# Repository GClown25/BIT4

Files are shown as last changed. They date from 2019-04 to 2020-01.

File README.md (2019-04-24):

# BIT4
BIT4 is a 4Bit microcontroller - fully programmable with only three buttons.

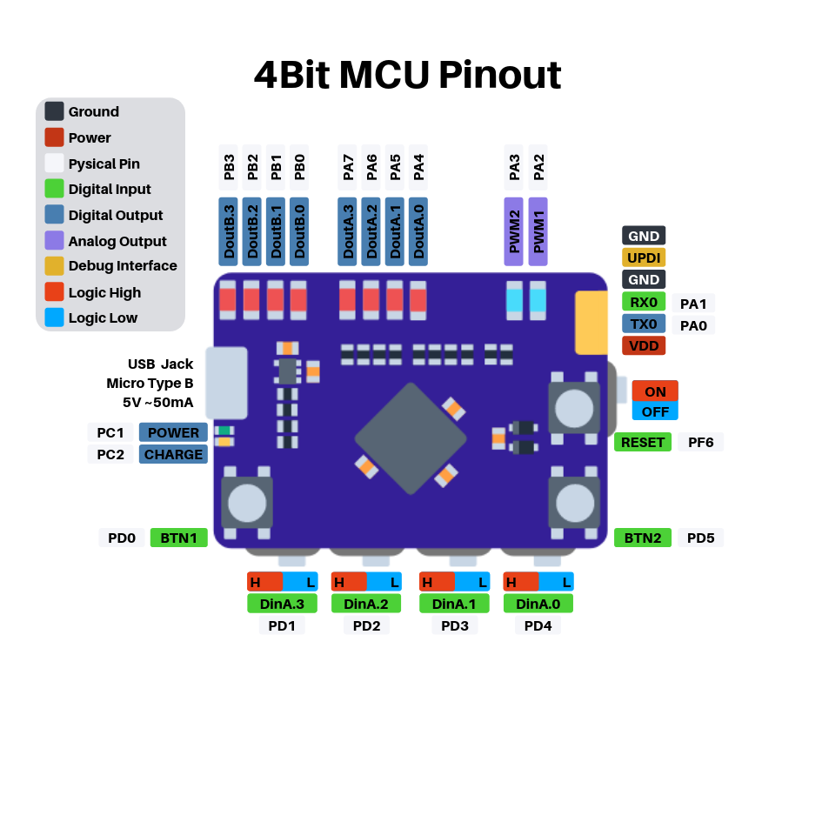
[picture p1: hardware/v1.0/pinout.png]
pinout


# Programming guide:

The BIT4 microcontroller has 256 Bytes of programm memory, split in 16 pages with each 16 instructions.
A instruction is 8bit wide and consists of an command and data:
\
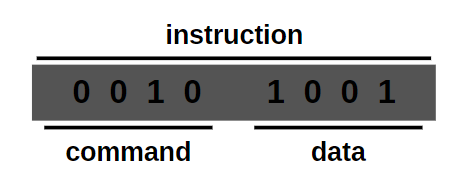
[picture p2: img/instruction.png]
instruction

\
To enter the programming mode, hold BTN2 down, press the RESET button once and then release BTN2.
In programming mode, step through the instructions with BTN2. When going to a new instruction, 
the leds will show the current address for a fraktion of a second.
With BTN1 the value of the command and data of the current instruction can be changed.
When stepping to a new address with BTN2, the instuction of the address above gets saved in the EEPROM.
At the end, press RESET to leave the programming mode and to start the programm execution.

## Instruction set explained:

- command 0x0: load a constant value to doutB
- command 0x1: load a constant value to doutA
- command 0x2: delay
- command 0x3: do a relative jump back
- command 0x4: load constant value to variable A
- command 0x5: load something with the value of variable A
- command 0x6: load the value of something into the variable A
- command 0x7: do arithmetic and logic operations with variable A (and B)
- command 0x8: set the high nibble of the address to jump to in absolute jump instructions
- command 0x9: do an absolute jump to the specified address
- command 0xA, 0xB: acts like a for loop. Every time this command is executed,
  if the variable C (or D) is greater than zero, an absolute jump to the specified address is done.
  Then the variable C (or D) gets decremented. 
- command 0xC: skip the next instruction if the argument is true
- command 0xD: call a function at the specified address
- command 0xE: return from the function call
- command 0xF: sets the address of the virtual 4bit RAM. 
  The value stored in this address can be read with 0x6e and written with 0x50.

## Examples:

**Blinki:**

| address | instruction | comment |
| :--- | :--- | ---: |
| 0 | 1f |  turn all leds on doutA on |
| 1 | 28 | wait for 500ms |
| 2 | 10 | turn all leds on doutB off |
| 3 | 28 | wait for 500ms |
| 4 | 34 | relative jump -4 |

\
**Binary counter:**
\
https://www.youtube.com/watch?v=6CpZszKlP7Y

| address | instruction | comment |
| :--- | :--- | ---: |
| 0 | 5B | DoutB = A |
| 1 | 59 | PWM1 = A |
| 2 | 71 | A++ |
| 3 | 28 | wait for 500ms |
| 4 | 34 | relative jump -4 |

\
**Blinki with adjustable speed:**
\
https://www.youtube.com/watch?v=YPoedGGZs4g

| address | instruction | comment |
| :--- | :--- | ---: |
| **main:** |
| 0 | 10 | DoutA = 0x0 |
| 1 | d5 | call myWait |
| 2 | 1f | DoutA = 0xf |
| 3 | d5 | call myWait |
| 4 | 34 | relative jump -4 |
| **myWait:** |
| 5 | 64 | A = Din |
| 6 | 52 | C = A |
| 7 | 25 | wait for 50ms |
| 8 | a7 | for(C > 0; C--) jmp 7 |
| 9 | e0 | return |

\
**Credits:**\
The idea for this project came from the german microcontroller learning plattform "TPS" (http://elektronik-labor.de/Lernpakete/TPS/TPS0.html).

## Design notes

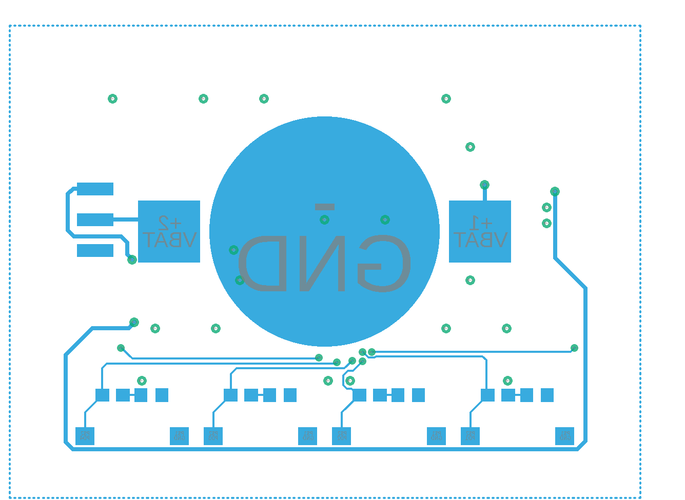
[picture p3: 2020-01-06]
hardware/v1.1b/layout_bot.png

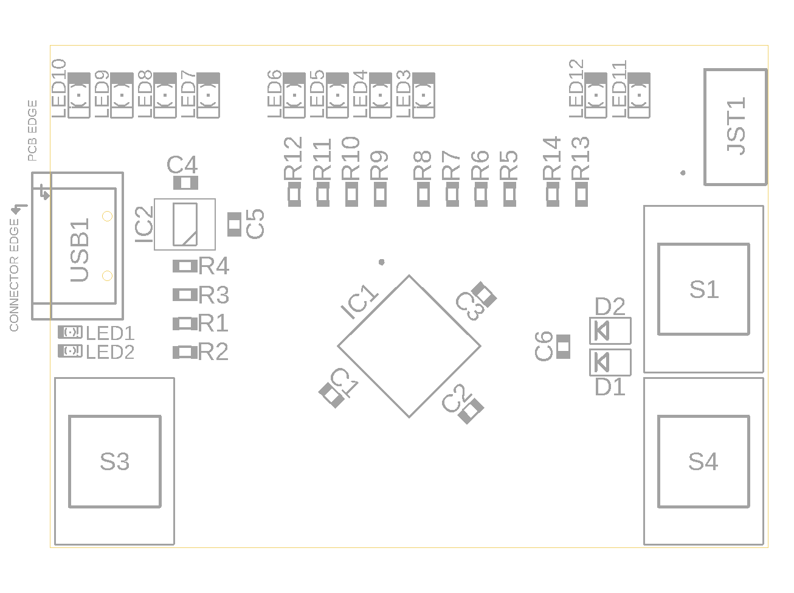
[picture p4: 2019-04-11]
hardware/v1.0/place_top.png

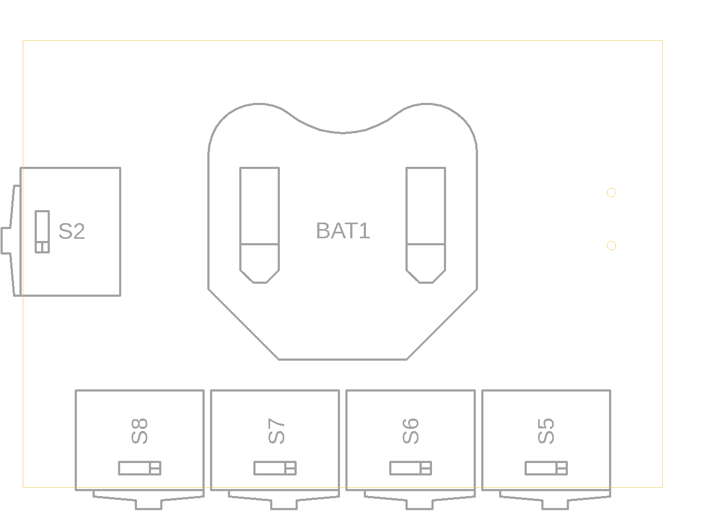
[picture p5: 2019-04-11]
hardware/v1.0/place_bot.png

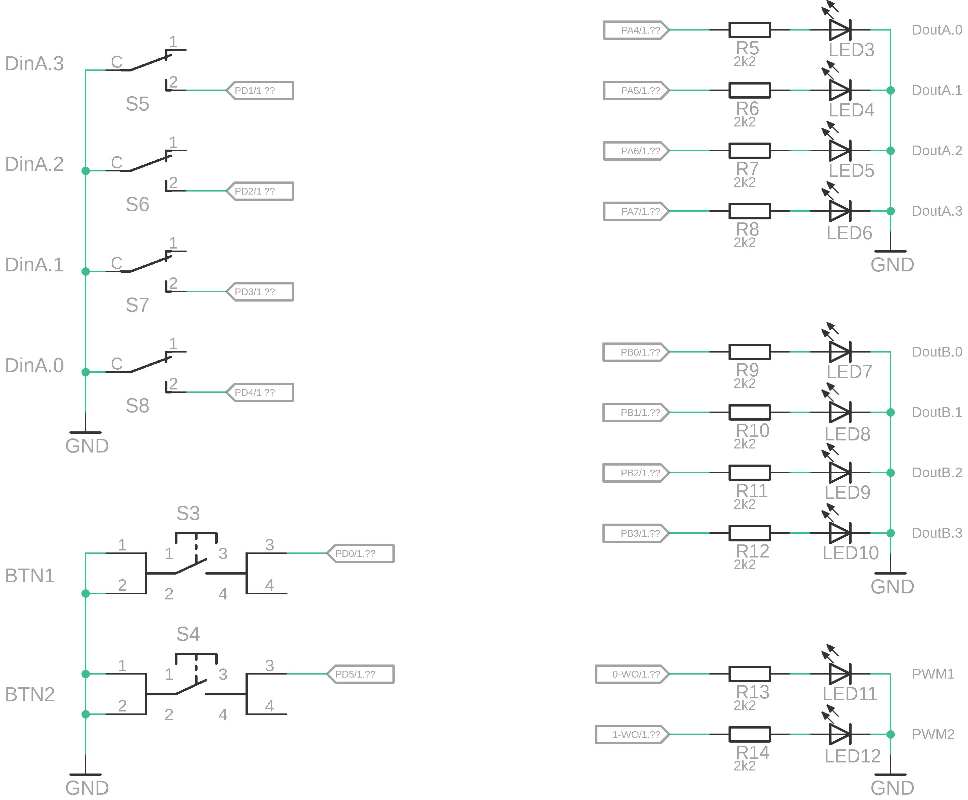
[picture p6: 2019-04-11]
hardware/v1.0/schematic3.png

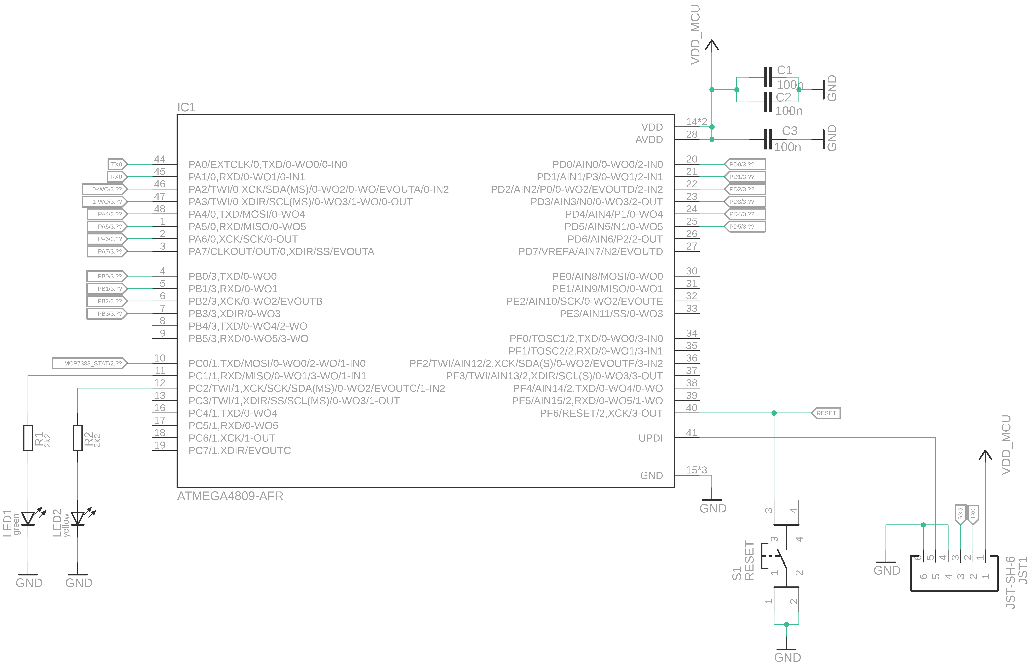
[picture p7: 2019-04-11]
hardware/v1.0/schematic1.png

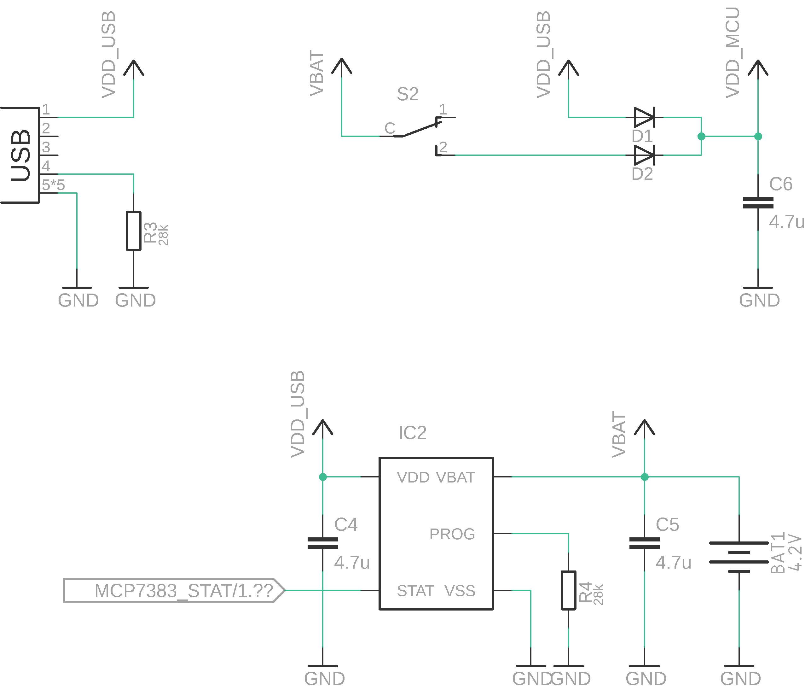
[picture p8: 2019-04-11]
hardware/v1.1b/schematic_2.png

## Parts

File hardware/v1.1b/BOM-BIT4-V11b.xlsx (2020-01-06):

pieces | identifier | name | package | prize/piece | prize | link
1 | IC1 | Atmega4809 | TQFP 48-Pin | 1.34 € | 1.34 € | https://www.mouser.at/ProductDetail/556-ATMEGA4809-AFR
1 | IC2 | MCP7383 Li-ion charger | SOT23-5 | 0.41 € | 0.41 € | https://www.reichelt.at/battery-management-ic-li-ion-sot-23-5-mcp-73831t-2aci-p217314.html?trstct=pos_0
1 | USB1 | micro usb type B | smd | 0.78 € | 0.78 € | https://www.mouser.at/ProductDetail/538-47346-0001
1 | JST1 | JST-SH-6 connector | smd 90° | 0.56 € | 0.56 € | https://at.rs-online.com/web/p/leiterplatten-header/5468827/?searchHistory=%7B%22enabled%22%3Atrue%7D
1 | BAT1 | cell battery clip 20mm | smd | 0.25 € | 0.25 € | https://www.mouser.at/ProductDetail/712-BAT-HLD-001
2 | D1, D2 | MBR0530T1G schottky diode | SOD-123 | 0.07 € | 0.14 € | https://www.reichelt.at/schottkydiode-30-v-0-5-a-sod-123-mbr0530t1g-ons-p219621.html?&trstct=pos_0
3 | S1, S3, S4 | button 6x6x4.3 mm | smd | 0.28 € | 0.84 € | https://www.reichelt.at/taster-smd-1-schliesser-no-omr-b3fs-1012p-p243058.html?&trstct=pol_2
4 | U$1-U$4 | button 3x6x2.5mm | smd | 0.03 € | 0.12 € | https://www.banggood.com/100pcs-3-x-6-x-2_5mm-DC-12V-0_5A-SMD-Tact-Push-Button-Switch-p-1202259.html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
1 | S2 | switch 10x6.5x2.5 mm | smd | 1.00 € | 1.00 € | https://www.reichelt.at/schiebeschalter-1x-um-liegend-smd-ss-smd402-p112181.html?&trstct=pol_1
1 | LED1 | led green | 0603 | 0.07 € | 0.07 € | https://www.reichelt.at/led-smd-0603-gruen-16-mcd-100-evl-19-21sygc-p231658.html?&trstct=pos_0
1 | LED2 | led yellow | 0603 | 0.07 € | 0.07 € | https://www.reichelt.at/led-smd-0603-gelb-16-mcd-100-evl-19-21uyc-s5-p231661.html?&trstct=pos_0
4 | LED3-LED6 | led DoutA | 1206 | 0.08 € | 0.32 € | https://www.reichelt.at/led-smd-1206-rot-62-mcd-60-evl-11-21sdrc-p231607.html?&trstct=pos_0
4 | LED7-LED10 | led DoutB | 1206 | 0.08 € | 0.32 € | https://www.reichelt.at/led-smd-1206-rot-62-mcd-60-evl-11-21sdrc-p231607.html?&trstct=pos_0
4 | LED13-LED16 | led DinA | 1206 | 0.09 € | 0.36 € | https://www.reichelt.at/led-smd-1206-gruen-44-mcd-60-evl-11-21sygc-s2-p231611.html?r=1
2 | LED11, LED12 | led PWM | 1206 | 0.36 € | 0.72 € | https://www.reichelt.at/led-smd-1206-blau-44-mcd-20-evl-11-21ubc-c4-p231612.html?&trstct=pos_0
2 | R3, R4 | resistor 28k | 0603 | 0.02 € | 0.04 € | https://www.reichelt.at/smd-widerstand-0603-28-0-kohm-100-mw-1-rnd-0603-1-28k-p213128.html?trstct=pos_0
16 | R1, R2, R5-R18 | resistor 2k2 | 0603 | 0.02 € | 0.32 € | https://www.reichelt.at/smd-widerstand-0603-2-2-kohm-100-mw-1-rnd-0603-1-2-2k-p183061.html?trstct=pos_0
4 | R19-R22 | resistor 100R | 0603 | 0.02 € | 0.08 € | https://www.reichelt.at/smd-widerstand-0603-100-ohm-100-mw-1-rnd-0603-1-100-p183013.html?trstct=pol_0
3 | C4-C6 | capacitor 4u7 | 0603 | 0.07 € | 0.21 € | https://www.reichelt.at/vielschicht-kerko-4-7-f-10v-85-c-kem-x5r0603-4-7u-p207009.html?&trstct=pos_0
7 | C1-C3, C7-C10 | capacitor 100n | 0603 | 0.02 € | 0.14 € | https://www.reichelt.at/smd-vielschicht-keramikkondensator-100n-10-x7r-g0603-100n-p31873.html?trstct=pos_0
 |  |  |  |  | 8.09 €

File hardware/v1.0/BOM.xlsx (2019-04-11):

pieces | identifier | name | package | prize/piece | prize | link
1 | IC1 | Atmega4809 | TQFP 48-Pin | 1.61 € | 1.61 € | https://at.rs-online.com/web/p/products/1753197/
1 | IC2 | MCP7383 Li-ion charger | SOT23-5 | 0.41 € | 0.41 € | https://www.reichelt.at/battery-management-ic-li-ion-sot-23-5-mcp-73831t-2aci-p217314.html?trstct=pos_0
1 | USB1 | micro usb type B | smd | 1.84 € | 1.84 € | https://at.rs-online.com/web/p/micro-usb-steckverbinder/8183361/?searchHistory=%7B%22enabled%22%3Atrue%7D
1 | JST1 | JST-SH-6 connector | smd 90° | 0.56 € | 0.56 € | https://at.rs-online.com/web/p/leiterplatten-header/5468827/?searchHistory=%7B%22enabled%22%3Atrue%7D
1 | BAT1 | cell battery clip 20mm | smd | 0.33 € | 0.33 € | https://www.reichelt.at/knopfzellenclip-fuer-20-mm-smd-kzh-20smd-p56574.html?&trstct=pol_8
2 | D1, D2 | MBR0530T1G schottky diode | SOD-123 | 0.07 € | 0.14 € | https://www.reichelt.at/schottkydiode-30-v-0-5-a-sod-123-mbr0530t1g-ons-p219621.html?&trstct=pos_0
3 | S1, S3, S4 | button 6x6x4.3 mm | smd | 0.28 € | 0.84 € | https://www.reichelt.at/taster-smd-1-schliesser-no-omr-b3fs-1012p-p243058.html?&trstct=pol_2
5 | S2, S5-S8 | switch 10x6.5x2.5 mm | smd | 1.00 € | 5.00 € | https://www.reichelt.at/schiebeschalter-1x-um-liegend-smd-ss-smd402-p112181.html?&trstct=pol_1
1 | LED1 | led green | 0603 | 0.07 € | 0.07 € | https://www.reichelt.at/led-smd-0603-gruen-16-mcd-100-evl-19-21sygc-p231658.html?&trstct=pos_0
1 | LED2 | led yellow | 0603 | 0.07 € | 0.07 € | https://www.reichelt.at/led-smd-0603-gelb-16-mcd-100-evl-19-21uyc-s5-p231661.html?&trstct=pos_0
8 | LED3-LED10 | led (any color) | 1206 | 0.10 € | 0.80 € | https://www.reichelt.at/led-smd-1206-gelb-29-mcd-60-evl-11-21uyc-s52-p231614.html?&trstct=pos_0
2 | LED11, LED12 | led (any color) | 1206 | 0.36 € | 0.72 € | https://www.reichelt.at/led-smd-1206-blau-44-mcd-20-evl-11-21ubc-c4-p231612.html?&trstct=pos_0
2 | R3, R4 | resistor 28k | 0603 | 0.02 € | 0.04 € | https://www.reichelt.at/smd-widerstand-0603-28-0-kohm-100-mw-1-rnd-0603-1-28k-p213128.html?trstct=pos_0
12 | R1, R2, R4-R14 | resistor 2k2 | 0603 | 0.02 € | 0.24 € | https://www.reichelt.at/smd-widerstand-0603-2-2-kohm-100-mw-1-rnd-0603-1-2-2k-p183061.html?trstct=pos_0
3 | C4-C6 | capacitor 4u7 | 0603 | 0.07 € | 0.21 € | https://www.reichelt.at/vielschicht-kerko-4-7-f-10v-85-c-kem-x5r0603-4-7u-p207009.html?&trstct=pos_0
3 | C1-C3 | capacitor 100n | 0603 | 0.02 € | 0.06 € | https://www.reichelt.at/smd-vielschicht-keramikkondensator-100n-10-x7r-g0603-100n-p31873.html?trstct=pos_0
 |  |  |  |  | 12.94 €

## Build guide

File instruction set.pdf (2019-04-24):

basic stuff | prog flow doing sth with variables | prog flow | for loop | prog flow function call and return | storage
command -> | 0 | 1 | 2 | 3 | 4 | 5 | 6 | 7 | 8 | 9 | A | B | C | D | E | F
data \/ | DoutB= | DoutA= | Wait | rel jump -n | A= | ... =A | A= ... | A= ... | Set Page | Jump to | C* | D* | Skip if ... | Call | Ret | Set RAM R/W Addr
0 | 0 | 0 | 1 ms | 0 | 0 | RAM = A | | | 0 | 0 | 0 | 0 | | 0 | 0 | 0
1 | 1 | 1 | 2 ms | 1 | 1 | B=A | A= B | A=A+1 | 1 | 1 | 1 | 1 | A>B | 1 | | 1
2 | 2 | 2 | 5 ms | 2 | 2 | C=A | A=C | A=A–1 | 2 | 2 | 2 | 2 | A<B | 2 | | 2
3 | 3 | 3 | 10 ms | 3 | 3 | D=A | A=D | A=A+B | 3 | 3 | 3 | 3 | A==B | 3 | | 3
4 | 4 | 4 | 20 ms | 4 | 4 | DoutA=A | A=Din | A=A–B | 4 | 4 | 4 | 4 | A != B | 4 | | 4
5 | 5 | 5 | 50 ms | 5 | 5 | DoutA.0=A.0 | A=Din.0 | A= A*B | 5 | 5 | 5 | 5 | A = 0 | 5 | | 5
6 | 6 | 6 | 100 ms | 6 | 6 | DoutA.1=A.0 | A=Din.1 | A=A/B | 6 | 6 | 6 | 6 | A != 0 | 6 | | 6
7 | 7 | 7 | 200 ms | 7 | 7 | DoutA.2=A.0 | A=Din.2 | A=A And B | 7 | 7 | 7 | 7 | | 7 | | 7
8 | 8 | 8 | 500 ms | 8 | 8 | DoutA.3= A.0 | A=Din.3 | A=A Or B | 8 | 8 | 8 | 8 | Din.0=0 | 8 | | 8
9 | 9 | 9 | 1 s | 9 | 9 | PWM1=A | | A= A Xor B | 9 | 9 | 9 | 9 | Din.1=0 | 9 | | 9
A | 10 | 10 | 2 s | 10 | 10 | PWM2=A | | A=Not A | A | A | A | A | Din.2=0 | A | | A
B | 11 | 11 | 5 s | 11 | 11 | DoutB=A | A = randNr | A = A mod B | B | B | B | B | Din.3=0 | B | | B
C | 12 | 12 | 10 s | 12 | 12 | DoutB.0=A.0 | A = DoutA | A = A << 1 | C | C | C | C | BTN1=0 | C | | C
D | 13 | 13 | 20 s | 13 | 13 | DoutB.1=A.0 | A = DoutB | A = A >> 1 | D | D | D | D | BTN2=0 | D | | D
E | 14 | 14 | 30 s | 14 | 14 | DoutB.2=A.0 | A = RAM | A = A <<B | E | E | E | E | BTN1=1 | E | | E
F | 15 | 15 | 60 s | 15 | 15 | DoutB.3= A.0 | A = RAM[B] | A = A >> B | F | F | F | F | BTN2=1 | F | | F

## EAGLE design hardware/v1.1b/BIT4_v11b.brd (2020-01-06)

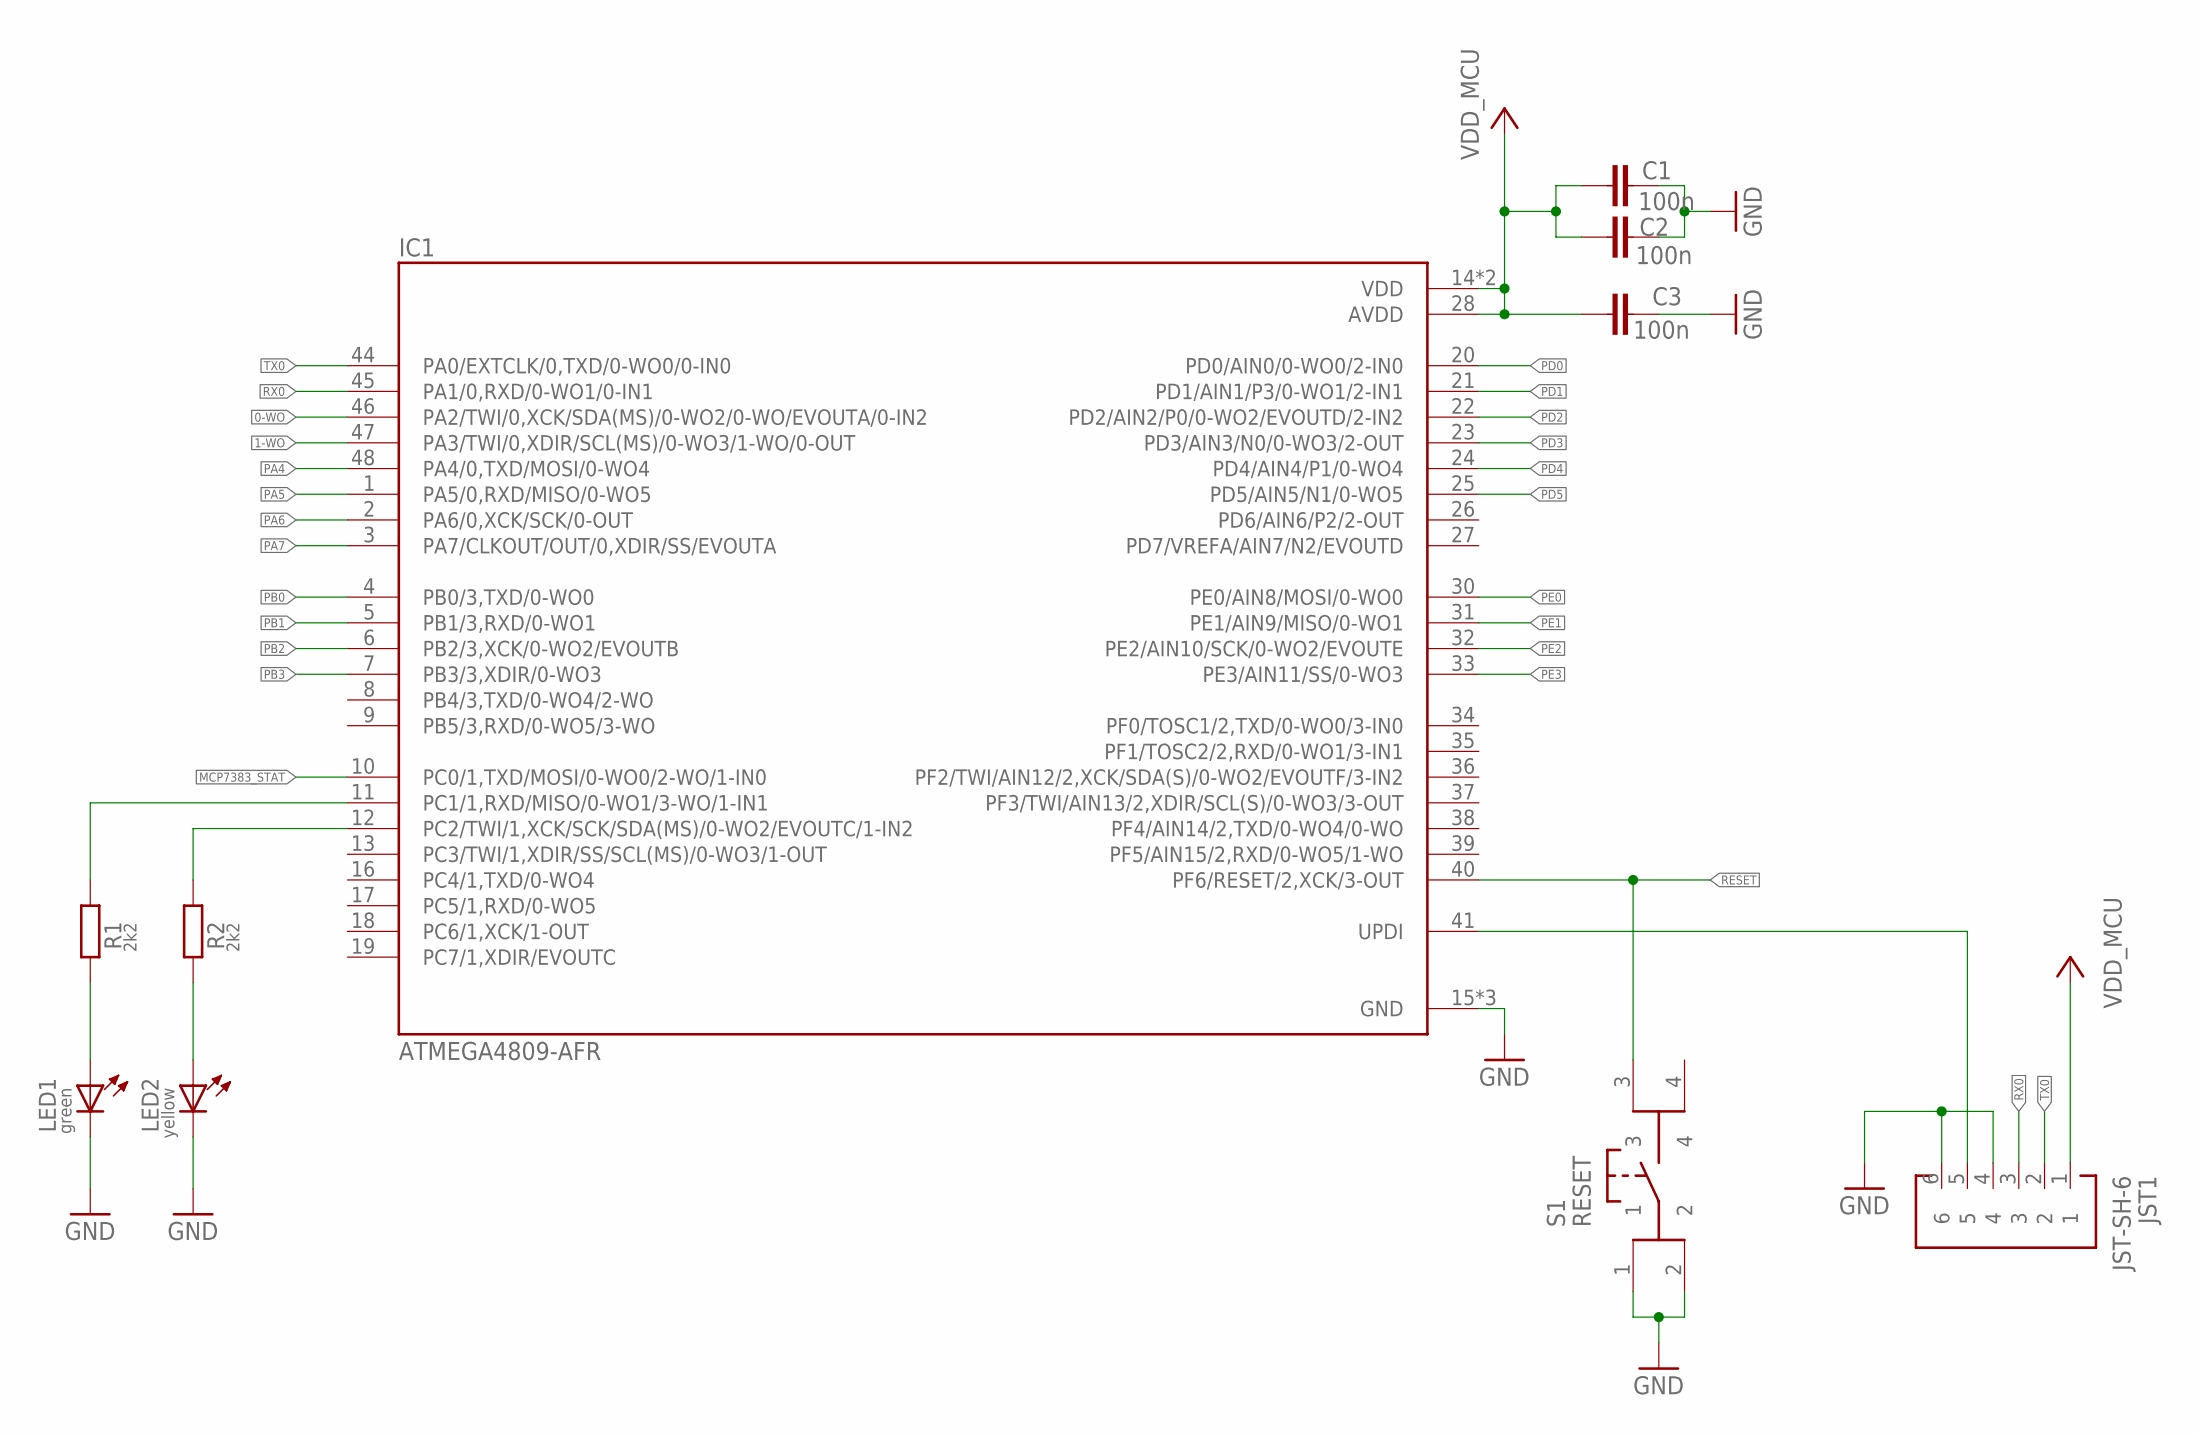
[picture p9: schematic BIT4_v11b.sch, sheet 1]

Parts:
C1, C2, C3: 100n; C0603
IC1: ATMEGA4809-AFR; QFP50P900X900X120-48N
JST1: JST-SH-6
LED1: green; LED_0603
LED2: yellow; LED_0603
R1, R2: 2k2; R0603
S1: RESET; B3FS-1012

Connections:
0-WO: IC1.46 (PA2/TWI/0,XCK/SDA(MS)/0-WO2/0-WO/EVOUTA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); also elsewhere on the board
1-WO: IC1.47 (PA3/TWI/0,XDIR/SCL(MS)/0-WO3/1-WO/0-OUT); also elsewhere on the board
GND: C1.2, C2.2, C3.2, IC1.15 (GND), IC1.29 (GND), IC1.43 (GND), JST1.4, JST1.6, LED1.C, LED2.C, S1.1, S1.2; also elsewhere on the board
MCP7383_STAT: IC1.10 (PC0/1,TXD/MOSI/0-WO0/2-WO/1-IN0); also elsewhere on the board
unnamed: LED2.A, R2.1
unnamed: LED1.A, R1.1
unnamed: IC1.12 (PC2/TWI/1,XCK/SCK/SDA(MS)/0-WO2/EVOUTC/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), R2.2
unnamed: IC1.11 (PC1/1,RXD/MISO/0-WO1/3-WO/1-IN1), R1.2
PA4: IC1.48 (PA4/0,TXD/MOSI/0-WO4); also elsewhere on the board
PA5: IC1.1 (PA5/0,RXD/MISO/0-WO5); also elsewhere on the board
PA6: IC1.2 (PA6/0,XCK/SCK/0-OUT); also elsewhere on the board
PA7: IC1.3 (PA7/CLKOUT/OUT/0,XDIR/SS/EVOUTA); also elsewhere on the board
PB0: IC1.4 (PB0/3,TXD/0-WO0); also elsewhere on the board
PB1: IC1.5 (PB1/3,RXD/0-WO1); also elsewhere on the board
PB2: IC1.6 (PB2/3,XCK/0-WO2/EVOUTB); also elsewhere on the board
PB3: IC1.7 (PB3/3,XDIR/0-WO3); also elsewhere on the board
PD0: IC1.20 (PD0/AIN0/0-WO0/2-IN0); also elsewhere on the board
PD1: IC1.21 (PD1/AIN1/P3/0-WO1/2-IN1); also elsewhere on the board
PD2: IC1.22 (PD2/AIN2/P0/0-WO2/EVOUTD/2-IN2); also elsewhere on the board
PD3: IC1.23 (PD3/AIN3/N0/0-WO3/2-OUT); also elsewhere on the board
PD4: IC1.24 (PD4/AIN4/P1/0-WO4); also elsewhere on the board
PD5: IC1.25 (PD5/AIN5/N1/0-WO5); also elsewhere on the board
PE0: IC1.30 (PE0/AIN8/MOSI/0-WO0); also elsewhere on the board
PE1: IC1.31 (PE1/AIN9/MISO/0-WO1); also elsewhere on the board
PE2: IC1.32 (PE2/AIN10/SCK/0-WO2/EVOUTE); also elsewhere on the board
PE3: IC1.33 (PE3/AIN11/SS/0-WO3); also elsewhere on the board
RESET: IC1.40 (PF6/RESET/2,XCK/3-OUT), S1.3
RX0: IC1.45 (PA1/0,RXD/0-WO1/0-IN1), JST1.3
TX0: IC1.44 (PA0/EXTCLK/0,TXD/0-WO0/0-IN0), JST1.2
UPDI: IC1.41 (UPDI), JST1.5
VDD_MCU: C1.1, C2.1, C3.1, IC1.14 (VDD), IC1.28 (AVDD), IC1.42 (VDD), JST1.1; also elsewhere on the board

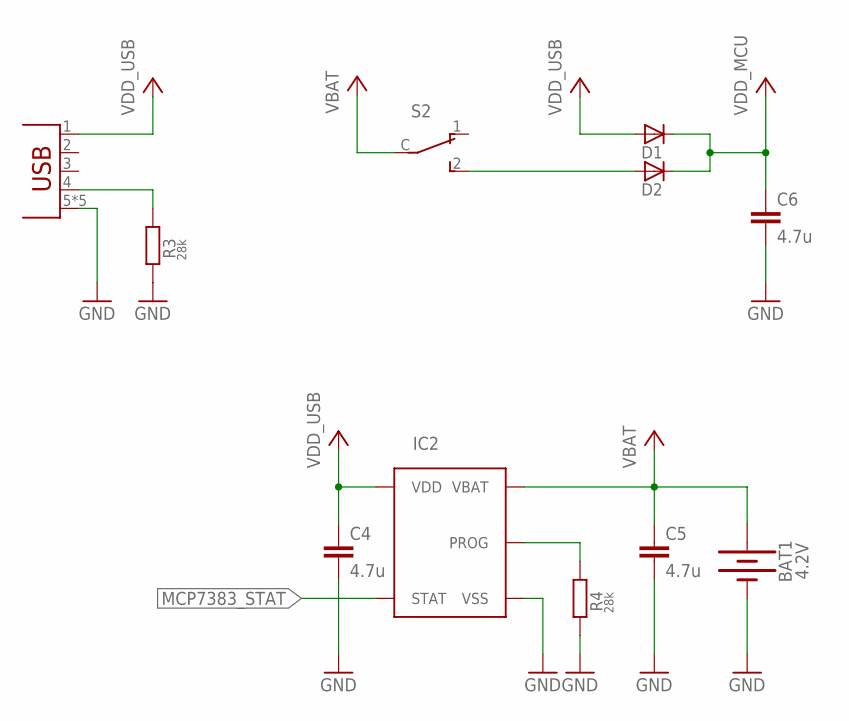
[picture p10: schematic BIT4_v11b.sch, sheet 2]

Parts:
BAT1: 4.2V; CELL-CLIP_PAD_20MM
C4, C5, C6: 4.7u; C0603
D1, D2: DIODE; MBR0530T1
IC2: MCP7383; SOT23-5
R3, R4: 28k; R0603
S2: SWITCH; ESP40XX
USB1: USB; 629105136821

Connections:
GND: BAT1.-, C4.2, C5.2, C6.2, IC2.2 (VSS), R3.1, R4.1, USB1.5 (GND), USB1.Z1 (GND), USB1.Z2 (GND), USB1.Z3 (GND), USB1.Z4 (GND); also elsewhere on the board
MCP7383_STAT: IC2.1 (STAT); also elsewhere on the board
unnamed: R3.2, USB1.4 (USBID)
unnamed: D2.P$1 (A), S2.2
unnamed: IC2.5 (PROG), R4.2
VBAT: BAT1.+1 (+), BAT1.+2 (+), C5.1, IC2.3 (VBAT), S2.C
VDD_MCU: C6.1, D1.P$2 (C), D2.P$2 (C); also elsewhere on the board
VDD_USB: C4.1, D1.P$1 (A), IC2.4 (VDD), USB1.1 (VBUS)

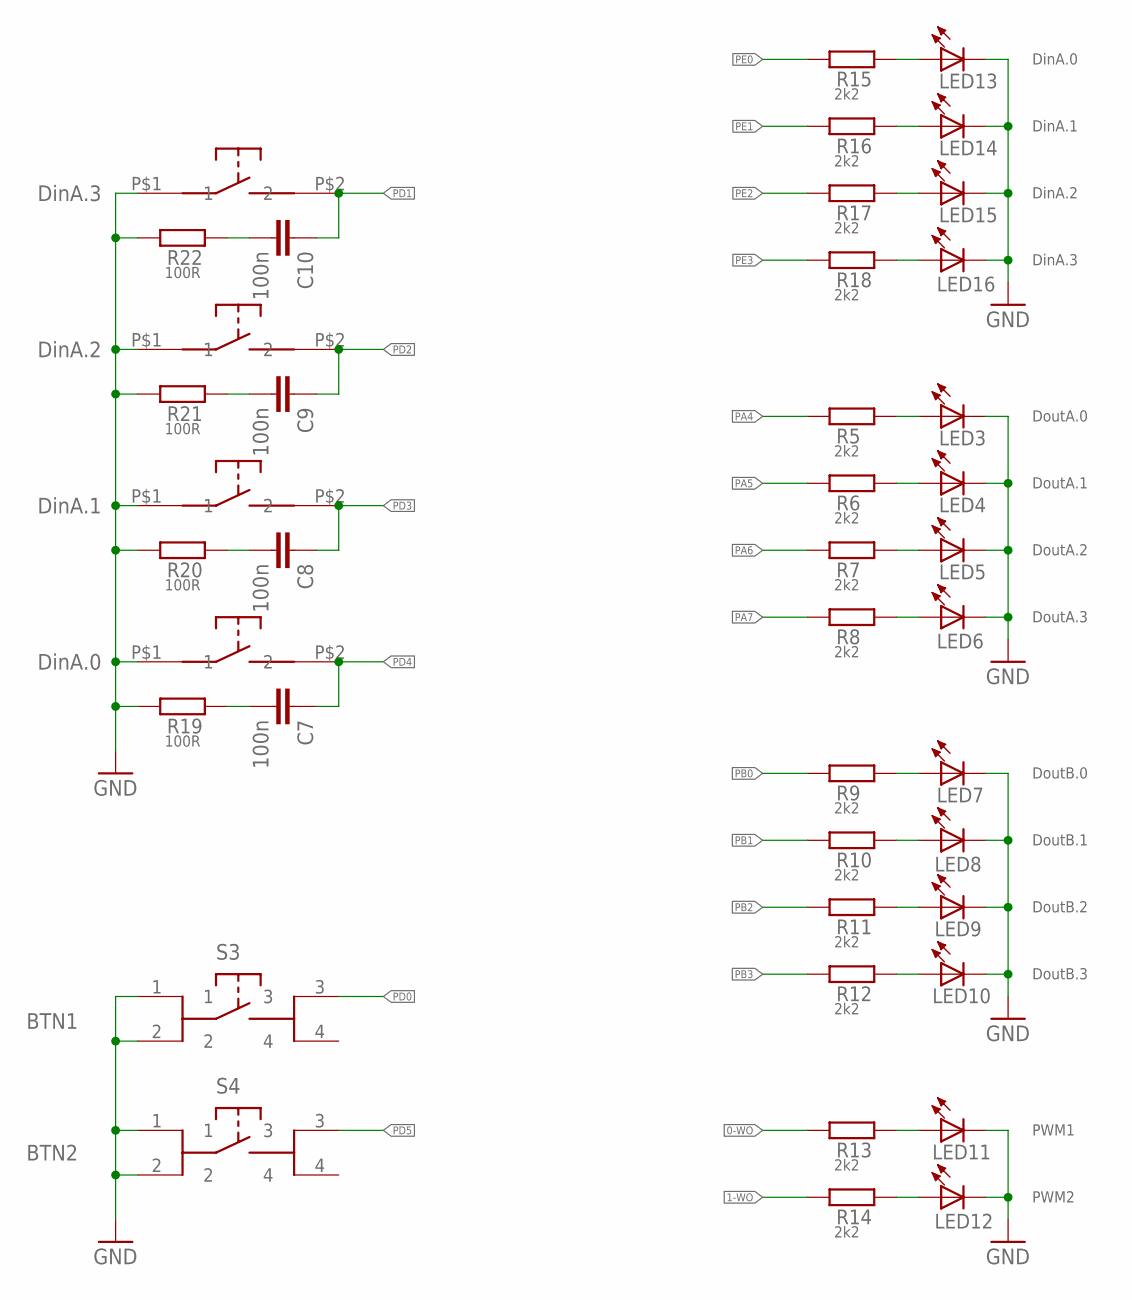
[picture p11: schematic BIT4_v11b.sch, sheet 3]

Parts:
C7, C8, C9, C10: 100n; C0603
LED3: DoutA.0; LED_1206
LED4: DoutA.1; LED_1206
LED5: DoutA.2; LED_1206
LED6: DoutA.3; LED_1206
LED7: DoutB.0; LED_1206
LED8: DoutB.1; LED_1206
LED9: DoutB.2; LED_1206
LED10: DoutB.3; LED_1206
LED11: PWM1; LED_1206
LED12: PWM2; LED_1206
LED13: DinA.0; LED_1206
LED14: DinA.1; LED_1206
LED15: DinA.2; LED_1206
LED16: DinA.3; LED_1206
R5, R6, R7, R8, R9, R10, R11, R12, R13, R14, R15, R16, R17, R18: 2k2; R0603
R19, R20, R21, R22: 100R; R0603
S3: BTN1; B3FS-1012
S4: BTN2; B3FS-1012
U$1: DinA.3; BTN_3X6X2.5
U$2: DinA.2; BTN_3X6X2.5
U$3: DinA.1; BTN_3X6X2.5
U$4: DinA.0; BTN_3X6X2.5

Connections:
0-WO: R13.1; also elsewhere on the board
1-WO: R14.1; also elsewhere on the board
GND: LED3.C, LED4.C, LED5.C, LED6.C, LED7.C, LED8.C, LED9.C, LED10.C, LED11.C, LED12.C, LED13.C, LED14.C, LED15.C, LED16.C, R19.1, R20.1, R21.1, R22.1, S3.1, S3.2, S4.1, S4.2, U$1.P$1 (1), U$2.P$1 (1), U$3.P$1 (1), U$4.P$1 (1); also elsewhere on the board
unnamed: LED13.A, R15.2
unnamed: LED14.A, R16.2
unnamed: LED15.A, R17.2
unnamed: LED16.A, R18.2
unnamed: C10.2, R22.2
unnamed: C9.2, R21.2
unnamed: C8.2, R20.2
unnamed: C7.2, R19.2
unnamed: LED3.A, R5.2
unnamed: LED4.A, R6.2
unnamed: LED5.A, R7.2
unnamed: LED6.A, R8.2
unnamed: LED7.A, R9.2
unnamed: LED8.A, R10.2
unnamed: LED9.A, R11.2
unnamed: LED10.A, R12.2
unnamed: LED11.A, R13.2
unnamed: LED12.A, R14.2
PA4: R5.1; also elsewhere on the board
PA5: R6.1; also elsewhere on the board
PA6: R7.1; also elsewhere on the board
PA7: R8.1; also elsewhere on the board
PB0: R9.1; also elsewhere on the board
PB1: R10.1; also elsewhere on the board
PB2: R11.1; also elsewhere on the board
PB3: R12.1; also elsewhere on the board
PD0: S3.3; also elsewhere on the board
PD1: C10.1, U$1.P$2 (2); also elsewhere on the board
PD2: C9.1, U$2.P$2 (2); also elsewhere on the board
PD3: C8.1, U$3.P$2 (2); also elsewhere on the board
PD4: C7.1, U$4.P$2 (2); also elsewhere on the board
PD5: S4.3; also elsewhere on the board
PE0: R15.1; also elsewhere on the board
PE1: R16.1; also elsewhere on the board
PE2: R17.1; also elsewhere on the board
PE3: R18.1; also elsewhere on the board

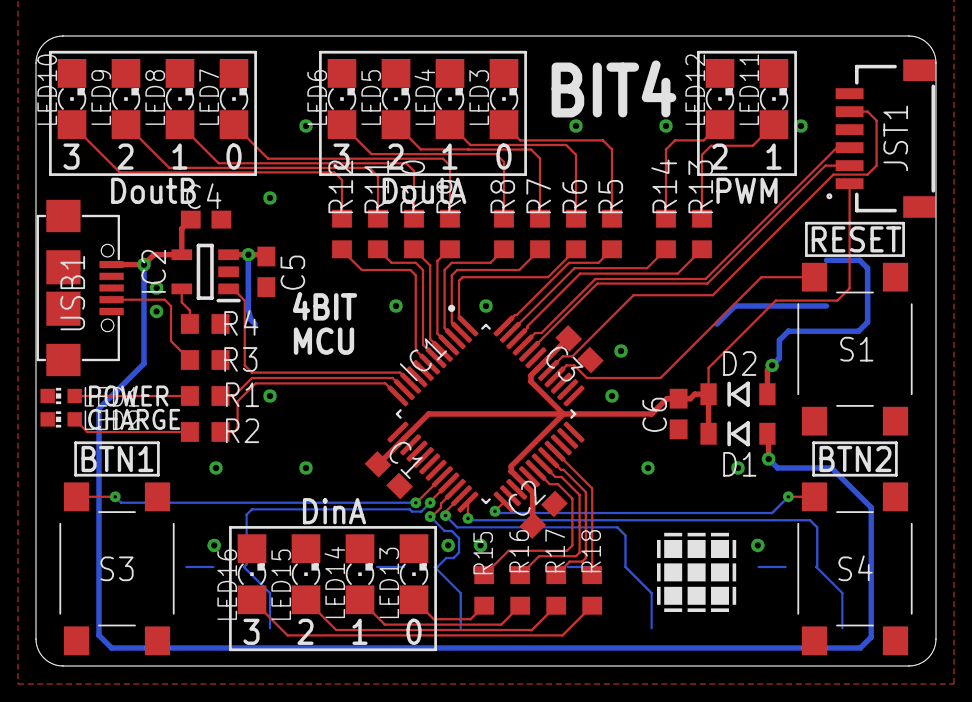
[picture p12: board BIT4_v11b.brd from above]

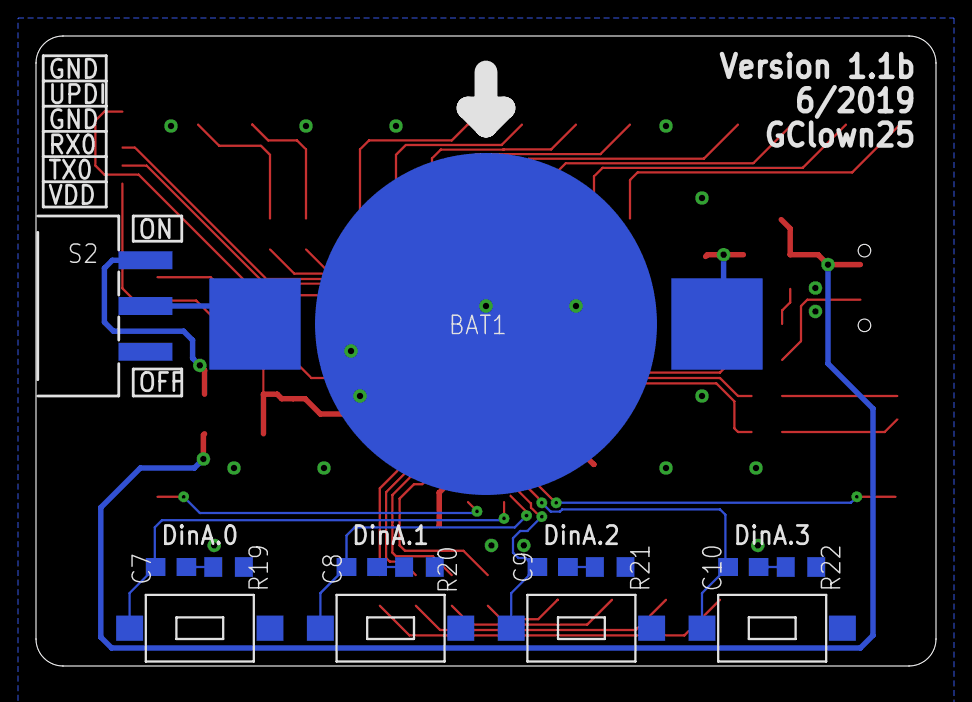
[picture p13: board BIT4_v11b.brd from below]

Board: 2 copper layers, 50.0 x 35.0 mm, 63 parts (14 on the bottom side), 54 nets.

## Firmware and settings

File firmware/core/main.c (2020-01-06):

/*
* main.c
*
* Created: 09.02.2019
* Author : GClown25
*
*
*	@info	Make sure the correct board version is defined in the
*			project properties (Allowed values are: BOARD_V10 or BOARD_V11B)
*
*/

#define F_CPU 5000000UL

#include <util/delay.h>
#include <avr/io.h>
#include <avr/interrupt.h>
#include <stdlib.h>

#include "core/tps.h"
#include "memory/eeprom.h"
#include "peripheral/gpio.h"
#include "peripheral/timer.h"
#include "peripheral/adc.h"
#include "common/randomSeed.h"

/* Size of the EEPROM in bytes */
#define MEMORY_SIZE 256

/* IOs */
GPIO_BTN mcpStat =	{ &PORTC.PIN0CTRL,	&PORTC.DIR,	&PORTC.IN,	PIN0_bp };
GPIO_BTN btn1 =		{ &PORTD.PIN0CTRL,	&PORTD.DIR,	&PORTD.IN,	PIN0_bp	};
GPIO_BTN btn2 =		{ &PORTD.PIN5CTRL,	&PORTD.DIR,	&PORTD.IN,	PIN5_bp };
GPIO_DOUT doutA =	{ &PORTA.OUT,	&PORTA.DIR,	NORMAL,	PIN4_bp };	
GPIO_DOUT doutB =	{ &PORTB.OUT,	&PORTB.DIR,	NORMAL,	PIN0_bp };
#ifdef BOARD_V10
GPIO_DIN dinA =		{ &PORTD.PIN1CTRL,	&PORTD.DIR,	&PORTD.IN,	REVERSED,	PIN1_bp };
#elif BOARD_V11B

GPIO_DIN dinA =		{ &PORTD.PIN1CTRL,	&PORTD.DIR,	&PORTD.IN,	REVERSED,	PIN1_bp, &PORTD.INTFLAGS, 
					{ &PORTE.OUT,	&PORTE.DIR,	NORMAL,	PIN0_bp }
					};
#endif

#define PWM1 TCB0
#define PWM2 TCB1

/* Global variables for BIT4 interpreter */
uint16_t progCounter = 0;
uint8_t page = 0;
uint8_t retVector = 0;
uint8_t instruction, command, data;
uint8_t buffer[MEMORY_SIZE];

int8_t varA = 0, varB = 0, varC = 0, varD = 0;

uint8_t ram[16] = {0};
uint8_t ramAddr = 0;

/* Lookup table for wait command */
const uint16_t waitCounterNr[] = {1, 2, 5, 10, 20, 50, 100, 200, 500, 1000, 2000, 5000, 10000, 20000, 30000, 60000};

/* Function prototypes */
static void programmInstruction();
static void  command0();
static void  command1();
static void  command2();
static void  command3();
static void  command4();
static void  command5();
static void  command6();
static void  command7();
static void  command8();
static void  command9();
static void  commandA();
static void  commandB();
static void  commandC();
static void  commandD();
static void  commandE();
static void  commandF();

void ( *commandFunc[])() = {
	command0,
	command1,
	command2,
	command3,
	command4,
	command5,
	command6,
	command7,
	command8,
	command9,
	commandA,
	commandB,
	commandC,
	commandD,
	commandE,
	commandF
};


int main(void){
	
	/* Clock init */
	CCP = CCP_IOREG_gc;
	CLKCTRL.MCLKCTRLA = CLKCTRL_CLKSEL_OSC20M_gc;
	CCP = CCP_IOREG_gc;
	CLKCTRL.MCLKCTRLB = CLKCTRL_PDIV_4X_gc | CLKCTRL_PEN_bm;
	
	/* turn on POWER incicator led */
	PORTC.DIRSET = PIN1_bm;
	PORTC.OUTSET = PIN1_bm;
	
#ifdef EXTENDED_DEBUG
	/* Init debug pin */
	PORTA.DIRSET = PIN0_bm;
	PORTA.OUTCLR = PIN0_bm;
#endif //EXTENDED_DEBUG

	/* Init MCP73831 charging indicator led */
	PORTC.DIRSET = PIN2_bm;
	
	/* Init MCP73831 Charge status sensing */
	gpio_btn_init(&mcpStat);
	
	CPUINT.CTRLA |= CPUINT_LVL0RR_bm; // Set the Round-robin Scheduling Enable bit
	CPUINT.LVL0PRI = PORTC_PORT_vect_num; //Set Interrupt priority
	PORTC.PIN0CTRL |= 0x01;	//Enable interrupt on both edges (mcpStat pin)
	
	if(gpio_btn_read(&mcpStat))
		PORTC.OUTCLR = PIN2_bm;
	else
		PORTC.OUTSET = PIN2_bm;
	
	sei();	//Enable interrupts
	
	/* Init peripherals */
	gpio_dout_init(&doutA);
	gpio_dout_init(&doutB);
	gpio_btn_init(&btn1);
	gpio_btn_init(&btn2);
	gpio_din_init(&dinA);
	
	timerb_initPWM(&PWM1);
	timerb_initPWM(&PWM2);
	
	adcInit();
	srand(getSeed());	//Get seed for random function (getSeed uses the ADC)
	adcDeInit();
	
	
	//Enter program mode
	if(gpio_btn_read(&btn2) == 0){
		
		//blink twice to visualize entering of prog mode
		for(int i = 0; i < 4; i++){
			uint8_t doutVal[] = {0xf, 0x0, 0xf, 0x0};
							
			gpio_dout_write(&doutA, doutVal[i]);
			gpio_dout_write(&doutB, doutVal[i]);
			_delay_ms(150);
		}
		
		while(progCounter < MEMORY_SIZE){
			programmInstruction();
			progCounter++;
		}
		
	//Enter intepretor mode
	}else{
		
		//Load instructions in buffer
		for(int i = 0; i < MEMORY_SIZE; i++){
			buffer[i] = EEPROM_read(i);
		}
		
		while(progCounter < MEMORY_SIZE){
				
#ifdef EXTENDED_DEBUG
			PORTA.OUTTGL = PIN0_bm;
#endif //EXTENDED_DEBUG

			tps_splitInstruction(buffer[progCounter], &command, &data);
			
			( *(commandFunc[command]))();
			
		}
			
	}
	
}


//load const val to doutB port
void command0(){
	gpio_dout_write(&doutB, data);
	progCounter++;
}

//load const val to doutA port
void command1(){
	gpio_dout_write(&doutA, data);
	progCounter++;
}

//delay
void command2(){
	for(uint16_t i = 1; i <= waitCounterNr[data]; i++)
	_delay_ms(1);
	progCounter++;
}

//relative jump back
void command3(){
	if(progCounter >= data )
	progCounter -= data;
	else
	progCounter = 0;
}

//load const val to A
void command4(){
	varA = data;
	progCounter++;
}

//load smth with the val of A
void command5(){
	switch(data){
		case 0x0:
			ram[ramAddr] = varA;
		break;
		case 0x1:
			varB = varA;
		break;		
		case 0x2:
			varC = varA;
		break;		
		case 0x3:
			varD = varA;
		break;		
		case 0x4:
			gpio_dout_write(&doutA, varA);
		break;		
		case 0x5:
			gpio_dout_writeBit(&doutA, varA, 0);
		break;	
		case 0x6:
			gpio_dout_writeBit(&doutA, varA, 1);
		break;		
		case 0x7:
			gpio_dout_writeBit(&doutA, varA, 2);
		break;	
		case 0x8:
			gpio_dout_writeBit(&doutA, varA, 3);
		break;	
		case 0x9:
			timerb_setDC(&PWM1, varA);
		break;
		case 0xA:
			timerb_setDC(&PWM2, varA);
		break;
		case 0xB:
			gpio_dout_write(&doutB, varA);
		break;
		case 0xC:
			gpio_dout_writeBit(&doutB, varA, 0);
		break;
		case 0xD:
			gpio_dout_writeBit(&doutB, varA, 1);
		break;
		case 0xE:
			gpio_dout_writeBit(&doutB, varA, 2);
		break;
		case 0xF:
			gpio_dout_writeBit(&doutB, varA, 3);
		break;
	}
	progCounter++;
}

//load smth into A
void command6(){
	switch(data){
		case 0x1:
			varA = varB;
		break;
		case 0x2:
			varA = varC;
		break;
		case 0x3:
			varA = varD;
		break;
		case 0x4:
			varA = gpio_din_read(&dinA);
		break;
		case 0x5:
			varA = gpio_din_readBit(&dinA, 0);
		break;
		case 0x6:
			varA = gpio_din_readBit(&dinA, 1);
		break;
		case 0x7:
			varA = gpio_din_readBit(&dinA, 2);
		break;
		case 0x8:
			varA = gpio_din_readBit(&dinA, 3);
		break;
		case 0xB:
			varA = rand() % 16;
		break;
		case 0xC:
			varA = gpio_dout_read(&doutA);
		break;
		case 0xD:
			varA = gpio_dout_read(&doutB);
		break;
		case 0xE:
			varA = ram[ramAddr] & 0xf;
		break;
		case 0xF:
			varA = ram[varB] & 0xf;
		break;
	}
	progCounter++;
}

//Do calculations with A (and B)
void command7(){
switch(data){
	case 0x1:
		if(varA < 15)
			varA++;
		else
			varA = 0;
	break;
	case 0x2:
		if(varA > 0)
			varA--;
		else
			varA = 15;
	break;
	case 0x3:
		varA = tps_add(varA, varB);
	break;
	case 0x4:
		varA = tps_subtract(varA, varB);
	break;
	case 0x5:
		varA = tps_multiply(varA, varB);
	break;
	case 0x6:
		varA = tps_divide(varA, varB);
	break;
	case 0x7:
		varA = (varA & varB);
	break;
	case 0x8:
		varA = (varA | varB);
	break;
	case 0x9:
		varA = (varA ^ varB) & 0xf;
	break;
	case 0xA:
		varA = (~varA) & 0xf;
	break;
	case 0xB:
		varA = tps_mod(varA, varB);
	break;
	case 0xC:
		varA = tps_shiftLeft(varA, 1);
	break;
	case 0xD:
		varA = tps_shiftRight(varA, 1);
	break;
	case 0xE:
		varA = tps_shiftLeft(varA, varB);
	break;
	case 0xF:
		varA = tps_shiftRight(varA, varB);
	break;
}
progCounter++;
}

//Set page for absolute jumps
void command8(){
	page = data;
	progCounter++;
}

//Do an absolute jump
void command9(){
	progCounter = (page << 4) | data;
}

//Do an absolute jump C times 
void commandA(){
	if(varC > 0){
		varC--;
		progCounter = (page << 4) | data;
	}else{
		progCounter++;
	}
}

//Do an absolute jump D times 
void commandB(){
	if(varD > 0){
		varD--;
		progCounter = (page << 4) | data;
	}else{
		progCounter++;
	}
}

//Skip if
void commandC(){
	switch(data){
		case 0x1:
		if(varA > varB)
			progCounter++;
		break;
		case 0x2:
		if(varA < varB)
			progCounter++;
		break;
		case 0x3:
		if(varA == varB)
			progCounter++;
		break;
		case 0x4:
		if(varA != varB)
			progCounter++;
		break;
		case 0x5:
		if(varA == 0)
			progCounter++;		
		break;
		case 0x6:
		if(varA != 0)
			progCounter++;		
		break;
		case 0x7:
		break;
		case 0x8:
		if(gpio_din_readBit(&dinA, 0) == 0)
			progCounter++;		
		break;
		case 0x9:
		if(gpio_din_readBit(&dinA, 1) == 0)
			progCounter++;
		break;
		case 0xA:
		if(gpio_din_readBit(&dinA, 2) == 0)
			progCounter++;
		break;
		case 0xB:
		if(gpio_din_readBit(&dinA, 3) == 0)
			progCounter++;
		break;
		case 0xC:
		if(gpio_btn_read(&btn1) == 0)
			progCounter++;
		break;
		case 0xD:
		if(gpio_btn_read(&btn2) == 0)
			progCounter++;
		break;
		case 0xE:
		if(gpio_btn_read(&btn1) == 1)
			progCounter++;
		break;
		case 0xF:
		if(gpio_btn_read(&btn2) == 1)
			progCounter++;
		break;
	}
	progCounter++;
}

//Call
void commandD(){
	retVector = progCounter;
	progCounter = (page << 4) | data;
}

//Return
void commandE(){
	progCounter = retVector + 1;
}

//Set the RAM r/w Address
void commandF(){
	ramAddr = data;
	progCounter++;
}


void programmInstruction(){
	bool lockCommand = false, lockData = false;
	
	instruction = EEPROM_read(progCounter);
	tps_splitInstruction(instruction, &command, &data);
	
	//************************************************************************************************* Show adress
	gpio_dout_write(&doutA, 0x00);
	gpio_dout_write(&doutB, 0x00);
	_delay_ms(100);
	gpio_dout_write(&doutA, progCounter);		//display low nibble of current address for some ms
	gpio_dout_write(&doutB, progCounter>>4);	//display high nibble of current address for some ms
	_delay_ms(300);
	gpio_dout_write(&doutA, 0x00);
	gpio_dout_write(&doutB, 0x00);
	_delay_ms(100);
	
	//************************************************************************************************* Show and modify command	
	gpio_dout_write(&doutB, command);	//display COMMAND of current address
	
	while(gpio_btn_read(&btn2) == 0);	//wait till button2 released
	_delay_ms(50);	//Debounce

	while(gpio_btn_read(&btn2) == 1){	//while button2 is released
		
		if(gpio_btn_read(&btn1) == 0){	//if button1 is pressed: if it's the first time set command to 0, otherwise increment it
			if(lockCommand == false){
				command = 0;
				lockCommand = true;
				}else{
				command++;
			}
			gpio_dout_write(&doutB, command);
			_delay_ms(50);	//Debounce
			while(gpio_btn_read(&btn1) == 0);	//wait till button1 is released
			_delay_ms(50);	//Debounce
		}
		
	}
	gpio_dout_write(&doutB, 0x00);
		
	//************************************************************************************************* Show and modify data
	gpio_dout_write(&doutA, data);	//display DATA of current address
	
	_delay_ms(50);	//Debounce
	while(gpio_btn_read(&btn2) == 0);	//wait till button2 released
	_delay_ms(50);	//Debounce
	
	while(gpio_btn_read(&btn2) == 1){	//while button2 is released
		
		if(gpio_btn_read(&btn1) == 0){	//if button1 is pressed: if it's the first time set data to 0, otherwise increment it
			if(lockData == false){
				data = 0;
				lockData = true;
				}else{
				data++;
			}
			gpio_dout_write(&doutA, data);
			_delay_ms(50);	//Debounce
			while(gpio_btn_read(&btn1) == 0);	//wait till button1 is released
			_delay_ms(50);	//Debounce
		}
		
	}
	gpio_dout_write(&doutA, 0x00);

	//************************************************************************************************* Optional: write to EEPROM
	if(lockCommand || lockData){
		tps_unifyInstruction(&instruction, command, data);
		EEPROM_write(progCounter, instruction);
		
		gpio_dout_write(&doutA, 0x00);
		gpio_dout_write(&doutB, 0x00);
		_delay_ms(700);	
	}


}


//Update MCP73831 Charge status led 
ISR(PORTC_PORT_vect){
	if(gpio_btn_read(&mcpStat))
		PORTC.OUTCLR = PIN2_bm;
	else
		PORTC.OUTSET = PIN2_bm;	
		
	PORTC.INTFLAGS = PIN0_bm;
}

#ifdef BOARD_V11B
ISR(PORTD_PORT_vect){
	
	/* Toggle the bit in the shadow register if the corresponding Din Button got pressed */
	for(int i = 0; i  <= 3; i++){	
		if(*dinA.intflags & (1 << (dinA.pin0 + i)) ){
			if(dinA.sequence == NORMAL)
				gpio_dout_toggleBit(&dinA.shadowReg, i);
			else
				gpio_dout_toggleBit(&dinA.shadowReg, 3U-i);
			
			*dinA.intflags = 1 << (dinA.pin0 + i);
		}
	}
	
}
#endif

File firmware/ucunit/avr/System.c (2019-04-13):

/*****************************************************************************
 *                                                                           *
 *  uCUnit - A unit testing framework for microcontrollers                   *
 *                                                                           *
 *  (C) 2007 - 2008 Sven Stefan Krauss                                       *
 *                  https://www.ucunit.org                                   *
 *                                                                           *
 *  File        : System.c                                                   *
 *  Description : System dependent functions used by uCUnit.                 *
 *                This file has to be customized for your hardware.         *
 *  Author      : Sven Stefan Krauss                                         *
 *  Contact     : www.ucunit.org                                             *
 *                                                                           *
 *****************************************************************************/

/*
 * This file is part of ucUnit.
 *
 * You can redistribute and/or modify it under the terms of the
 * Common Public License as published by IBM Corporation; either
 * version 1.0 of the License, or (at your option) any later version.
 *
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
 * It may also be available at the following URL:
 *       http://www.opensource.org/licenses/cpl1.0.txt
 *
 * If you cannot obtain a copy of the License, please contact the
 * author.
 */

#define F_CPU 20000000UL

#include <avr/io.h>

#include <stdio.h>
#include <stdlib.h>
#include "../System.h"



#define USART_BAUD_RATE(BAUD_RATE) ((float)(F_CPU * 64 / (16 *(float)BAUD_RATE)) + 0.5)

/* Stub: Initialize your hardware here */
void System_Init(void)
{
	//Disable Clk Prescaler (F_CPU = 20MHz)
	CCP = 0xd8;
	CLKCTRL.MCLKCTRLB = 0x00;
	
	//Initialize UART
	/*//for discovery kit
	PORTB.DIR |= PIN0_bm;
	USART3.BAUD = (uint16_t)USART_BAUD_RATE(9600);
	USART3.CTRLB |= USART_TXEN_bm;
	*/
	
	//for custom pcb
	PORTA.DIR |= PIN0_bm;
	USART0.BAUD = (uint16_t)USART_BAUD_RATE(115200);
	USART0.CTRLB |= USART_TXEN_bm;
	
	
	printf("Init of hardware finished.\n");
}

/* Stub: Shutdown your hardware here */
void System_Shutdown(void)
{

	/* asm("\tSTOP"); */
	printf("System shutdown.\n");
	exit(0);
}

/* Stub: Resets the system */
void System_Reset(void)
{
	/* Stub: Reset the hardware */
	/* asm("\tRESET"); */
	printf("System reset.\n");
	exit(0);
}

/* Stub: Put system in a safe state */
void System_Safestate(void)
{
	/* Disable all port pins */
	/* PORTA = 0x0000; */
	/* PORTB = 0x0000; */
	/* PORTC = 0x0000; */

	/* Disable interrupts */
	/* DIE(); */

	/* Put processor into idle state */
	/* asm("\tIDLE"); */
	printf("System safe state.\n");
	exit(0);
}

void uart_putc(char c)
{
// for discovery kit
// 	while (!(USART3.STATUS & USART_DREIF_bm))
// 	{
// 		;
// 	}
// 	USART3.TXDATAL = c;

// for custom pcb
	while (!(USART0.STATUS & USART_DREIF_bm))
	{
		;
	}
	USART0.TXDATAL = c;
}


/* Stub: Transmit a string to the host/debugger/simulator */
void System_WriteString(char * s)
{
	while(*s)
	{
		uart_putc(*s);
		s++;
	}
}

void System_WriteInt(int n)
{
	uint8_t buffer[10];
	itoa(n, buffer, 10);
	System_WriteString(buffer);
}

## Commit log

2019-04-11 Added hardware v1.0
    [BOM.xlsx, TPS_v1.brd, TPS_v1.sch]
2019-04-27 Updated hardware
    -changed clearance for default netclass to 5mil
    [TPS_v1.brd, TPS_v1.sch]
2019-07-07 Added debug pin support
2019-08-09 Added v1.1b hardware
    [BIT4_v11b.brd, BIT4_v11b.sch, BOM-BIT4-V11b.xlsx]
